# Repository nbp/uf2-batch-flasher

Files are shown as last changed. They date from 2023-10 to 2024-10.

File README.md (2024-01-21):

# UF2 Batch Flasher

The UF2 Batch Flasher is meant to provide a way to loop over up to 64 devices,
in order to flash all the 64 devices with a single
[UF2](https://github.com/microsoft/uf2) image. Using a Raspberry Pi Pico, and 64
USB A ports, the RP2040 will select one port at a time, and copy the transmitted
image to each device.

The alternative is to find the next cable, find the board at the end of it,
press a button, plug the cable while pressing the button, type a command / drag
a file over, unplug the device and repeat this 63 times. Not only this error
prone but this is time intensive and would probably take half an hour to iterate
over that many devices manually.

Picture of the First version of the UF2 Batch Flasher board

# Building the Hardware

The board design is designed using [KiCad](https://www.kicad.org/) and the
sources are located under the PCB directory. The Vendor links to Mouser are
listed as part of the component descriptions, and as of beginning of 2024, there
is [approximately 270€ of components and
PCB](https://www.nbp.name/projects/uf2-batch-flasher/#bill-of-material) to build
a single one.

# Building the Firmware

The firmware dependencies are managed with [Nix](https://nixos.org/) and
composed of the [Pico-SDK](https://github.com/raspberrypi/pico-sdk),
[Cyw43-driver](https://github.com/georgerobotics/cyw43-driver),
[LwIP](https://github.com/lwip-tcpip/lwip),
[TinyUSB](https://github.com/hathach/tinyusb) and
[Pico-PIO-USB](https://github.com/sekigon-gonnoc/Pico-PIO-USB).

In the root of the repository, type the following command to start a development
environment:

```shell
$ nix develop
```

This development environement will setup the expected environment variable and
provide a few useful functions such as `build` and `flash`. Other commands for
debugging are available such as `start_uart`, `start_openocd` and
`start_gdb_core0`, and listed in `firmware/shell.nix`.

Before building, you should configure the Wifi network credential by creating
the file `firmware/wifi.cmake`. A template file is available at
`firmware/wiki.cmake.template`.

To build just type `build` in this new environement and it would invoke `cmake`
and generate its output in the `_build` directory.

Once everything is built, plug the Raspberry Pi Pico W while pressing the
BOOTSEL button in order to flash it with the newly built firmware.

To flash, type `flash` in the build environment. This command invoke picotool as
a super user, to have access to usb devices. This will ask for your user
credential in order to flash the image.

# Debugging

Once the image is flashed, if all is good a web page would be served by the Pico
W, at the IP of the device on the registered network. The firmware also has UART
output on pins 16 and 17 in case of problems with the network stack.

Using the debug probes, one can connect to the within the development
environment with the `start_openocd` and `start_gdb_core0` to debug the Web
server and `start_gdb_core1` to debug the USB Host. The UART output can be
watched with `start_uart`.

# Using

Once powered, a web page is provided by the device, which list the status of the
USB as they are iterated over.

First drag and drop a UF2 image in the dedicated area and the click the "Flash
All" button. The web page would then iterate over the 64 USB ports, check if any
devices are connected, and if any flash the image on each of them.

The status of the flashing process then updates as it goes the status of the USB
which are listed on the page.

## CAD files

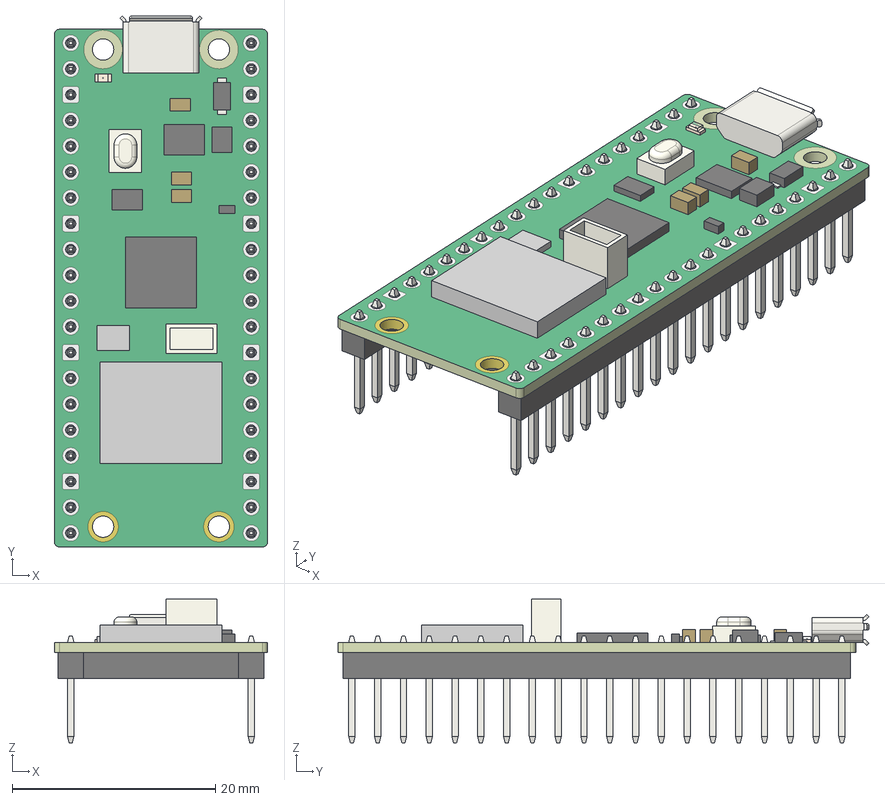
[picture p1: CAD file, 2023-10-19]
pcb/imports/RaspberryPi_Pico_STEP/RaspberryPi_Pico_WH_Socketed.step
21.0 x 52.3 x 14.1 mm
Pico_WH_Board
C1_47u
C2_47u
C21_47u
D1_MBR120VLSFT1G
D2_QSME-C194_Base
D2_QSME-C194_Phosphor
D2_QSME-C194_Lens
J1_690T505-x62-01x
J2_BM03B-SRSS-TB
L1_2u2
Q1_DMG1012T
SH1_CYW43439
SW1_TP-1221U-K9K5325
U1_RP2040
U2_RT6154AGQW
U3_W25Q16JVUXIQ
X1_X12M000000S096
DIP-40_W17.78mm_Header

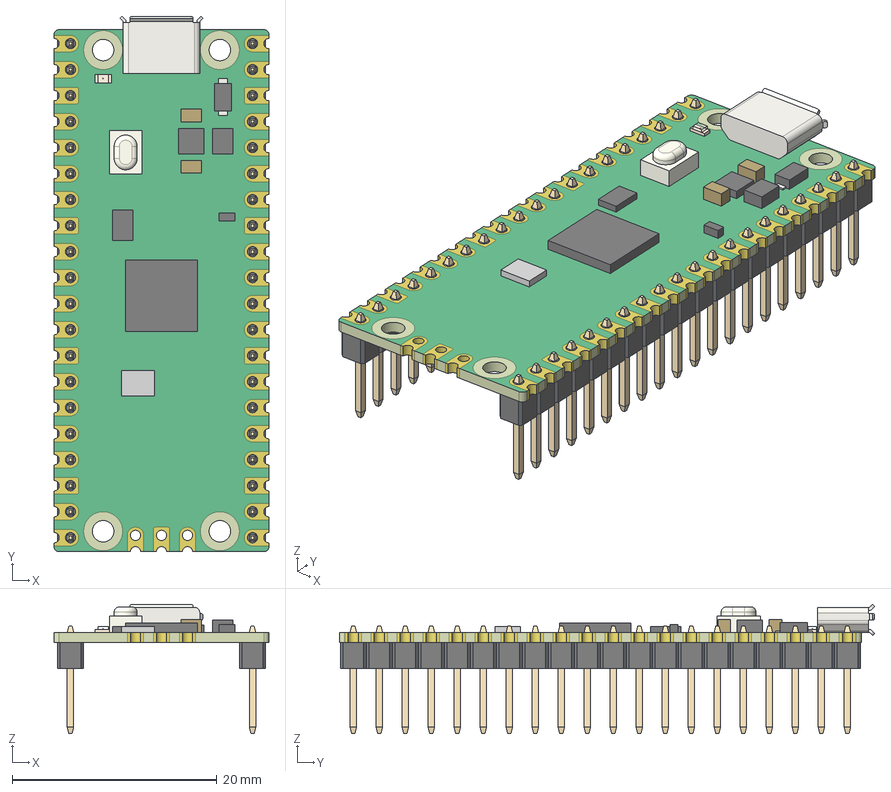
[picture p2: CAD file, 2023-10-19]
pcb/imports/RaspberryPi_Pico_STEP/RaspberryPi_Pico_AddedHeaders.step
21.0 x 52.3 x 12.6 mm
Pico_Board
C1_47u
C2_47u
D1_MBR120VLSFT1G
D2_QSME-C194_Base
D2_QSME-C194_Phosphor
D2_QSME-C194_Lens
J1_690T505-x62-01x
L1_2u2
Q1_DMG1012T
SW1_TP-1221U-K9K5325
U1_RP2040
U2_RT6150B-33GQW
U3_W25Q16JVUXIQ
X1_X12M000000S096
SIP-20_Header x 2

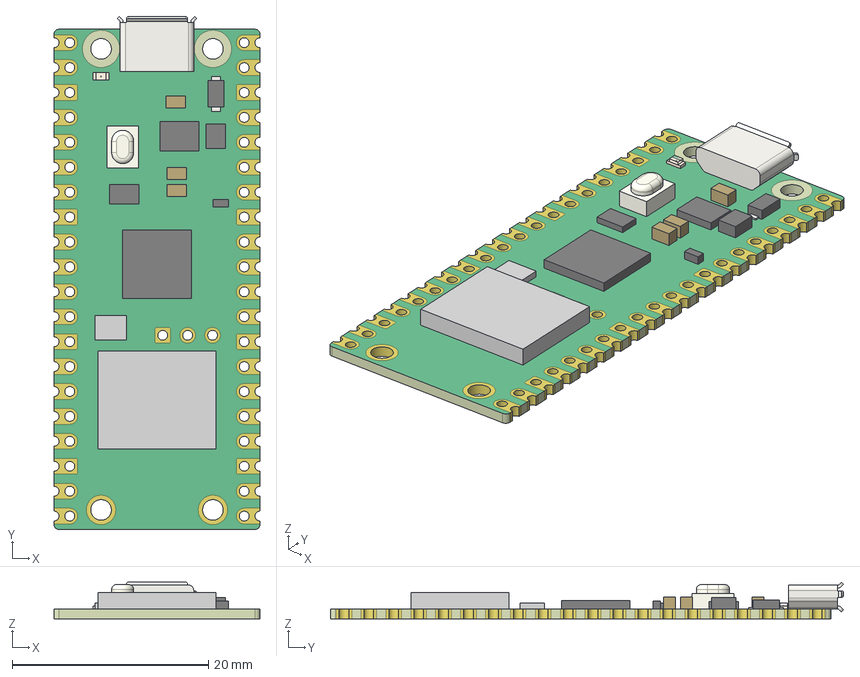
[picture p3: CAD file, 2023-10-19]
pcb/imports/RaspberryPi_Pico_STEP/RaspberryPi_Pico_W.step
21.0 x 52.3 x 3.75 mm
Pico_W_Board
C1_47u
C2_47u
C21_47u
D1_MBR120VLSFT1G
D2_QSME-C194_Base
D2_QSME-C194_Phosphor
D2_QSME-C194_Lens
J1_690T505-x62-01x
L1_2u2
Q1_DMG1012T
SH1_CYW43439
SW1_TP-1221U-K9K5325
U1_RP2040
U2_RT6154AGQW
U3_W25Q16JVUXIQ
X1_X12M000000S096

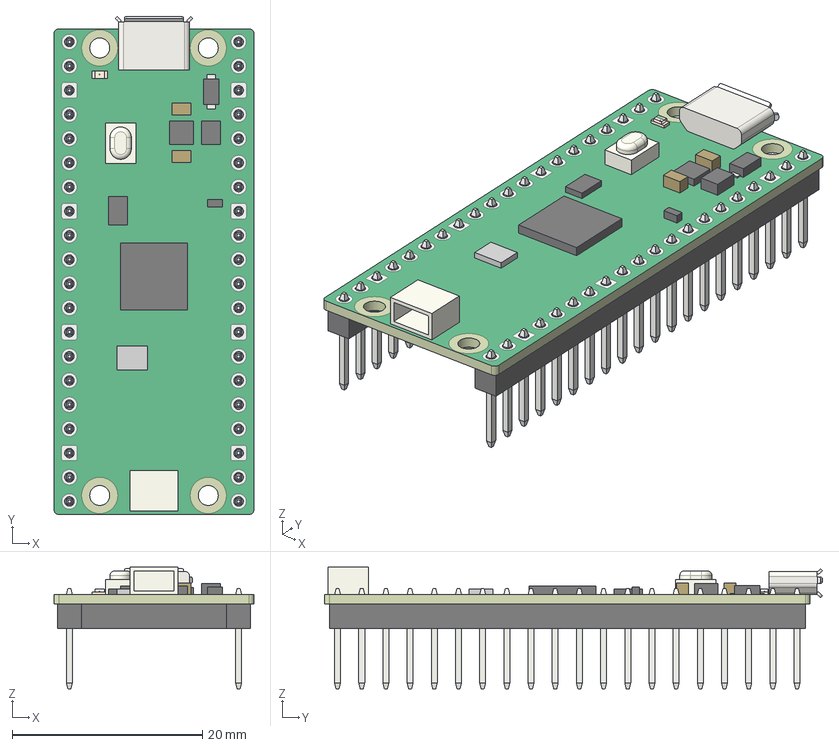
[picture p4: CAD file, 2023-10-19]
pcb/imports/RaspberryPi_Pico_STEP/RaspberryPi_Pico_H_Socketed.step
21.0 x 52.3 x 12.8 mm
Pico_H_Board
C1_47u
C2_47u
D1_MBR120VLSFT1G
D2_QSME-C194_Base
D2_QSME-C194_Phosphor
D2_QSME-C194_Lens
J1_690T505-x62-01x
J2_BM03B-SRSS-TB
L1_2u2
Q1_DMG1012T
SW1_TP-1221U-K9K5325
U1_RP2040
U2_RT6150B-33GQW
U3_W25Q16JVUXIQ
X1_X12M000000S096
DIP-40_W17.78mm_Header

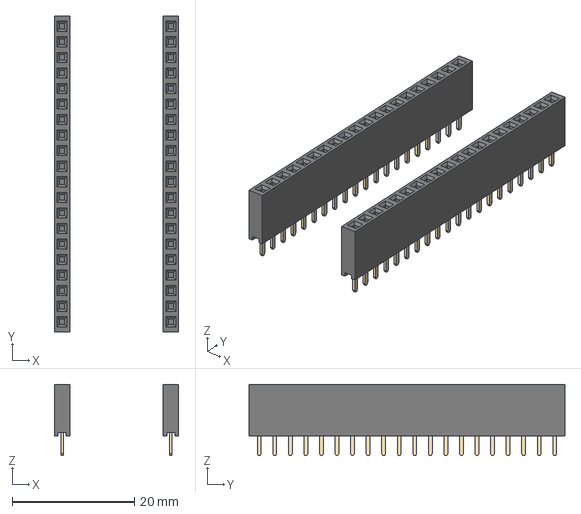
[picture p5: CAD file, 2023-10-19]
pcb/imports/RaspberryPi_Pico_STEP/DIP-40_W17.78mm_Socket.step
20.3 x 51.6 x 11.6 mm
SIP-20_Socket x 2

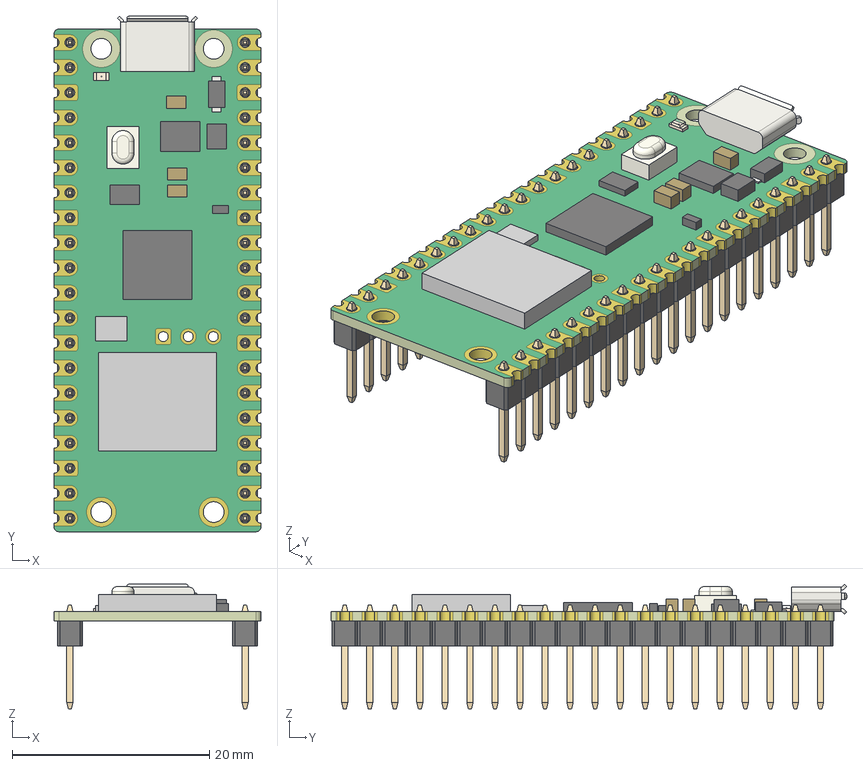
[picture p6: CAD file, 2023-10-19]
pcb/imports/RaspberryPi_Pico_STEP/RaspberryPi_Pico_W_AddedHeaders_Socketed.step
21.0 x 52.3 x 12.6 mm
Pico_W_Board
C1_47u
C2_47u
C21_47u
D1_MBR120VLSFT1G
D2_QSME-C194_Base
D2_QSME-C194_Phosphor
D2_QSME-C194_Lens
J1_690T505-x62-01x
L1_2u2
Q1_DMG1012T
SH1_CYW43439
SW1_TP-1221U-K9K5325
U1_RP2040
U2_RT6154AGQW
U3_W25Q16JVUXIQ
X1_X12M000000S096
SIP-20_Header x 2

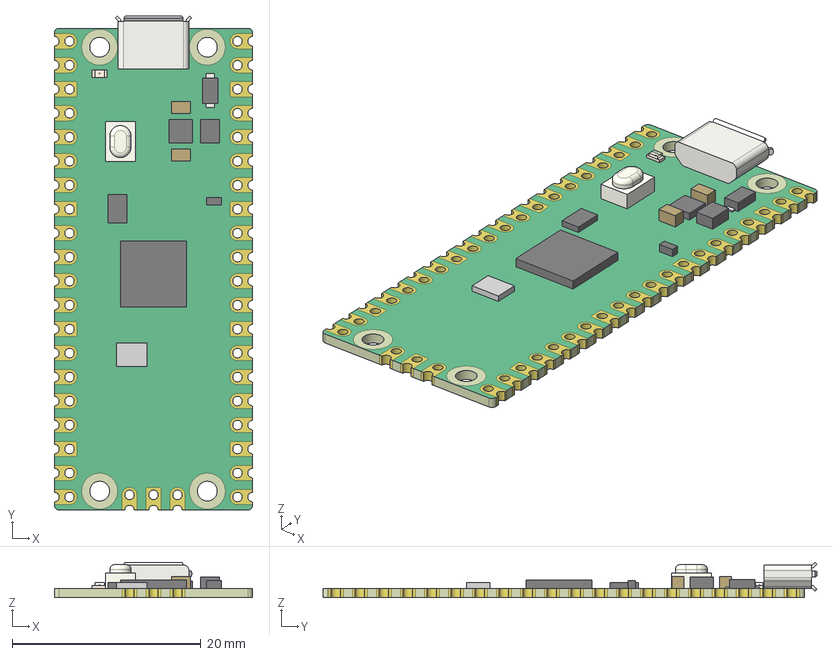
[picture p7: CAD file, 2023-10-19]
pcb/imports/RaspberryPi_Pico_STEP/RaspberryPi_Pico.step
21.0 x 52.3 x 3.75 mm
Pico_Board
C1_47u
C2_47u
D1_MBR120VLSFT1G
D2_QSME-C194_Base
D2_QSME-C194_Phosphor
D2_QSME-C194_Lens
J1_690T505-x62-01x
L1_2u2
Q1_DMG1012T
SW1_TP-1221U-K9K5325
U1_RP2040
U2_RT6150B-33GQW
U3_W25Q16JVUXIQ
X1_X12M000000S096

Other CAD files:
pcb/imports/RaspberryPi_Pico_STEP/RaspberryPi_Pico_WH.step
pcb/imports/RaspberryPi_Pico_STEP/RaspberryPi_Pico_H.step
pcb/imports/RaspberryPi_Pico_STEP/RaspberryPi_Pico_AddedHeaders_Socketed.step
pcb/imports/RaspberryPi_Pico_STEP/RaspberryPi_Pico_W_AddedHeaders.step

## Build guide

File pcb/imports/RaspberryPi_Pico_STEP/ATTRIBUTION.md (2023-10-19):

# Ki-Lime Pi Pico project attributions

## Peter S. Hollander

Model, footprint, and symbol [source files and documentation](https://gitlab.com/recursivenomad/ki-lime-pi-pico)
created and compiled by Peter S. Hollander between 2022 and 2023, and made
freely available under the [*MIT No Attribution*](https://opensource.org/license/mit-0/) license.

## Melissa Lee

Source project title "Ki-Lime Pi" created by Melissa Lee in 2022, and donated
with unconditional permission 🥧

## Markus Gyger

Comprehensive alternate pin definitions as defined in the RP2040 datasheet
inspired by the [schematic symbol](https://gitlab.com/mgyger/kicad-symbols/-/blob/pico/MCU_Module.kicad_sym)
created by Markus Gyger.

## Raspberry Pi

Original assets which were referenced for geometry/organisation (model, symbol,
footprint) acquired from Raspberry Pi in 2022 via:

- [Raspberry Pi Pico Datasheet](https://datasheets.raspberrypi.com/pico/pico-datasheet.pdf)
  - Pico Model: <https://datasheets.raspberrypi.com/pico/Pico-R3-step.zip>
- [Raspberry Pi Pico W Datasheet](https://datasheets.raspberrypi.com/picow/pico-w-datasheet.pdf)
  - Pico W Model: <https://datasheets.raspberrypi.com/picow/PicoW-step.zip>
- [RP2040 Datasheet](https://datasheets.raspberrypi.com/rp2040/rp2040-datasheet.pdf)
- [Hardware design with the RP2040](https://datasheets.raspberrypi.com/rp2040/hardware-design-with-rp2040.pdf)
  - RP2040 Symbol: <https://datasheets.raspberrypi.com/rp2040/Minimal-KiCAD.zip>
  - Pico Footprint: <https://datasheets.raspberrypi.com/rp2040/VGA-KiCAD.zip>
  - Pico W Footprint: <https://datasheets.raspberrypi.com/rp2040/VGA-PicoW-KiCAD.zip>

&nbsp;

# Tools utilized

- [KiCad](https://www.kicad.org/) - Footprint/symbol library design
- [FreeCAD](https://www.freecad.org/) - Parametric 3D modelling
  - [KiCad StepUp addon](https://github.com/easyw/kicadStepUpMod) - VRML model exporting
- [VSCodium](https://vscodium.com/) - VRML model material bulk editing

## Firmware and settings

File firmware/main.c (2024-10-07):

#include <stdbool.h>
#include <stdint.h>
#include <stddef.h>
#include <stdio.h>
#include <stdlib.h> // calloc

#include "hardware/xosc.h"
#include "pico/stdlib.h"

#include "pico/bootrom.h" // reset_usb_boot

#include "usb_host.h"
#include "tcp_server.h"
#include "web_server.h"
#include "pipe.h"
#include "stdio_web.h"

#include "input.h"

int main() {
  // Initialize the cristall oscillator. This is necessary to have a minimal
  // clock drift and jitter. Then initialize the clock at a multiple of the USB
  // 12 Mbits/s (x10) for bit-banging USB using PIO.
  xosc_init();
  set_sys_clock_khz(120000, true);

  // Create stdio drivers to output printed content to either a UART interface
  // or the web interface.
  stdio_uart_init();
  printf("STDIO UART initialized!\n");
  stdio_init_web();
  printf("STDIO Web initialized!\n");

  // Initialize pipe communication between the 2 cores.
  pipes_init();
  printf("Pipes across cores initialized!\n");

  // Setup USB devices.
  usb_host_setup();

#if defined(USE_TCP_SERVER)
  // Setup the TCP server.
  if (!tcp_server_setup()) {
    reset_usb_boot(0, 0);
    return 1;
  }

  // Core 0 main loop.
  printf("Starting TCP server loop.\n");
  tcp_server_loop();
#else
  // Setup the Web server.
  if (!web_server_setup()) {
    reset_usb_boot(0, 0);
    return 1;
  }

  // Core 0 main loop.
  printf("Starting Web server loop.\n");
  web_server_loop();
#endif

  // Use the on-board LED to report the data status of the USB line.
  led_init();


  return 0;
}

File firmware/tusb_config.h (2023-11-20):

// This file is used by TinyUSB library to register the configuration of the board.

#ifndef TUSB_CONFIG_H
#define TUSB_CONFIG_H

//--------------------------------------------------------------------
// COMMON CONFIGURATION
//--------------------------------------------------------------------

// defined by compiler flags for flexibility
#ifndef CFG_TUSB_MCU
#error CFG_TUSB_MCU must be defined
#endif

#ifndef CFG_TUSB_OS
#define CFG_TUSB_OS           OPT_OS_NONE
#endif

#ifndef CFG_TUSB_DEBUG
#ifndef NDEBUG
#define CFG_TUSB_DEBUG        3
#else
#define CFG_TUSB_DEBUG        0
#endif
#endif

//--------------------------------------------------------------------
// DEVICE CONFIGURATION (disabled)
//--------------------------------------------------------------------

// TODO: Enable the device CDC in order to switch to BOOTSEL mode as the
// stdio_usb library does using the baud rate, as well as re-implementing the
// stdio_usb output.

// RHPort number used for device can be defined by board.mk, default to port 0
#ifndef BOARD_TUD_RHPORT
#define BOARD_TUD_RHPORT      0
#endif

// RHPort max operational speed can defined by board.mk
#ifndef BOARD_TUD_MAX_SPEED
#define BOARD_TUD_MAX_SPEED   OPT_MODE_DEFAULT_SPEED
#endif

// Enable Device stack, Default is max speed that hardware controller could support with on-chip PHY
#define CFG_TUD_ENABLED       0
#define CFG_TUD_MAX_SPEED     BOARD_TUD_MAX_SPEED

// No Special section for the RP2040 while using DMA.
#define CFG_TUD_MEM_SECTION
#define CFG_TUD_MEM_ALIGN        __attribute__ ((aligned(4)))

#ifndef CFG_TUD_ENDPOINT0_SIZE
#define CFG_TUD_ENDPOINT0_SIZE    64
#endif

//------------- CLASS -------------//
#define CFG_TUD_CDC              0

// CDC FIFO size of TX and RX
#define CFG_TUD_CDC_RX_BUFSIZE   (TUD_OPT_HIGH_SPEED ? 512 : 64)
#define CFG_TUD_CDC_TX_BUFSIZE   (TUD_OPT_HIGH_SPEED ? 512 : 64)

// CDC Endpoint transfer buffer size, more is faster
#define CFG_TUD_CDC_EP_BUFSIZE   (TUD_OPT_HIGH_SPEED ? 512 : 64)

//--------------------------------------------------------------------
// HOST CONFIGURATION
//--------------------------------------------------------------------

// RHPort number used for host can be defined by board.mk, default to port 1
#ifndef BOARD_TUH_RHPORT
#define BOARD_TUH_RHPORT      1
#endif

// RHPort max operational speed can defined by board.mk
#ifndef BOARD_TUH_MAX_SPEED
#define BOARD_TUH_MAX_SPEED   OPT_MODE_DEFAULT_SPEED
#endif

// Enable Host stack, Default is max speed that hardware controller could support with on-chip PHY
#define CFG_TUH_ENABLED       1
#define CFG_TUH_MAX_SPEED     BOARD_TUH_MAX_SPEED

// Use pico-pio-usb as host controller for raspberry rp2040
#define CFG_TUH_RPI_PIO_USB   1

// Size of buffer to hold descriptors and other data used for enumeration
#define CFG_TUH_ENUMERATION_BUFSIZE 256

// No Special section for the RP2040 while using DMA.
#define CFG_TUH_MEM_SECTION
#define CFG_TUH_MEM_ALIGN           __attribute__ ((aligned(4)))

//------------- CLASS -------------//

// The UF2 batch flasher has 64 ports, which should be good enough for now.
#define CFG_TUH_HUB                 1
#define CFG_TUH_DEVICE_MAX          1
// (CFG_TUH_HUB ? 4 : 1) // hub typically has 4 ports
// #define CFG_TUH_MSC_MAXLUN          1 // typically 4

// Setup the current Raspberry Pi Pico to be used as a host for reading the
// file system of the device.
#define CFG_TUH_MSC                 1 // Mass Storage Class

// The RP2040 can be configured by the host to be reprogrammed, using the
// following macros:
//  - PICO_STDIO_USB_ENABLE_RESET_VIA_VENDOR_INTERFACE
//  - PICO_STDIO_USB_RESET_INTERFACE_SUPPORT_RESET_TO_BOOTSEL
//  - PICO_STDIO_USB_ENABLE_RESET_VIA_BAUD_RATE
//
// These macros are enabled by default when stdio_usb is used.
#define CFG_TUH_CDC                 1 // Communication Device Class

#define CFG_TUH_HID                 0 // keyboard / mouse
#define CFG_TUH_MIDI                0 // MIDI streaming interface.
#define CFG_TUH_VENDOR              0
// #define CFG_TUH_HID_EPIN_BUFSIZE    64
// #define CFG_TUH_HID_EPOUT_BUFSIZE   64

#endif // !TUSB_CONFIG_H

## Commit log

2023-10-19 Add UF2 Batch flasher board design
    [DIP-40_W17.78mm_Socket.step, RaspberryPi_Pico.step, RaspberryPi_Pico_AddedHeaders.step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]
2023-10-20 Add extra space and GND space below tracks.
2023-10-20 Briefly document and add the OSHW logo.
    [level1.kicad_sch, level2.kicad_sch, uf2-batch-flasher.kicad_sch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]
2023-10-20 Space out the SEL and Enable vias under the pico.
2023-10-20 Add alignment holes in the stencil.
2023-10-20 Move stencils alignment holes to be within the edges, using mounting holes and through holes of a few USB plugs.
2023-10-25 Alignment holes did not appear on the PCB preview of Aisler :/
2023-11-12 Fix Select pins mapping.
    Both the selector and demultiplexer are used to enable/disable the power
    and data pins. If the mapping of pins is not identical between the 2
    then we would enable the power pins of one USB port and the data pins of
    another.
    This patch changes that such that components which are closer to the
    Pico are using the high-power bits while components which are further
    down the tree are using the low bits. This way the enable pins are
    correctly ordered as specified in the datasheets of both components.
    Previously we were using the lowest bits, this would have been if
    the enable pins were mapped accordingly. Which was not the case.
    This change include changes in the schemat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
    [level1.kicad_sch, level2.kicad_sch, uf2-batch-flasher.kicad_sch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]
2023-11-18 Add first draft of the firmware.
    This firmware for the UF2 Batch Flasher provides a Web interface for the
    Raspberry Pi Pico W.
    The Web interface reports the status of the connected USB drives, and
    combined with the web client, the image to be flashed can be repeated to
    each device without adding cycles to the uf2 batch flasher flash.
    The uf2 batch flasher listen for HTTP request to wait for instructions
    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
2023-11-18 Handle cases where flashing the USB device does not complete.
2023-11-20 Enable float implementation to unblock pio usb.
    Pio USB implementation is using floating point operations to compute the number
    of cycles for the USB clock. Preventing uses of floating point caused the code
    to freeze and prevented the rest from being executed.
    [tusb_config.h]
2023-11-20 Use pins 16 & 17 for UART stdout/stdin.
    By default the pins 0 and 1 are used for UART, but these were conflicting with
    D+/D- pins.
    Moving UART to unassigned pins is useful to debug while the firmware is still in
    a prototype stage and the code is not fully working.
2023-11-20 Manually callback the polling of network activity.
    As this firmware uses both cores, in order to handle USB host interaction on
    core 1 and Web server interactions on core 0, we cannot rely on the threadsafe
    integration of cyw43 as this requires to have one other core available.
    Thus, instead we manually poll from the core 0 thread.
2023-11-20 Add debugging tools in the `nix develop` shell.
    minicom is useful for displaying the content coming through UART.
    openocd is useful for handling the debugprobe / picoprobe.
    gdb is useful for introspecting memory content.
2023-11-20 Properly report status via the ssi_handler.
    The ssi_handler had some first draft issues, this is now fixed by
    properly appending data and counting it properly. Also the stdout is now
    properly processed by renaming the file with one of the extensions
    supported by the SSI handler.
    Testing the USB with another Pico, everything seems to work almost out
    of the box, except that once switching the connected device to BOOTSEL
    mode, the TinyUSB host does not unmount the device and stays in CDC.
    [tusb_config.h]
2023-12-29 firmware: Fix enable pin logic, to match the hardware.
2023-12-29 firmware: Toggle USB data pins to move from CDC to MSC mount.
    The Raspberry Pi Pico / RP2040, has a mode where we can set the BAUD rate at
    1200Hz, to programmatically select the BOOTSEL mode, where it emulates a storage
    device.
    However TinyUSB does not take notice of this mode switch. Thus, we disable the
    data pins until TinyUSB unmount the device from the CDC mode, and renable them
    such that it can now consider it as an MSC mode. Such that we can flash the
    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
2023-12-29 firmware: Add missing select pin and fix off-by-1 on power and data pins.
    The missing select pin, and the off-by 1 issue caused the power pin to remain 0
    most of the time keeping all LED on.
2023-12-29 firmware: select.cgi was not found.
    When the JS code attempted to select the next device the web server did not
    respond because it was explicitly match for `select` without extensions.
2024-01-09 firmware: Avoid toogle to avoid accidental unbalanced of USB mount status.
2024-01-09 firmware: Stream bytes from POST to USB using pbuf from LwIP.
    Previously the data was being copied over from the POST request to a pipe held
    in memory, before being pulled by the USB host core which would send the bytes
    over to the USB device. This techniques caused some packets drop as the pipe was
    not being emptied fast enough and locked the receiving function.
    Locking the receving function caused some packets drops which caused the flashed
    image to be smaller than the original image which had to be flashed.
    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
2024-01-13 pcb: Update the directory in which the board is located.
    [DIP-40_W17.78mm_Socket.step, RaspberryPi_Pico.step, RaspberryPi_Pico_AddedHeaders.step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]
2024-01-14 web interface: Avoid failures, and allow reduced timeout.
    Previously the hardware could stop by waiting for a status code which had
    already been, then replaced. This implies that one would always wait for the
    last stable status instead of waiting for the first status code.
    By being able to wait for the last status code, we can increase the timer for
    the last status code, while decreasing the timer for the first status code by
    checking for inequality given that the most important status code are monotonic.
2024-01-14 firmware: Wait to account for the reboot in BOOTSEL mode.
    When we send the signal to put the device in BOOTSEL mode, by the time it
    finishes its initialization, TinyUSB would have recorded the device as nothing
    and then do not update its status after that.
    By disabling the USB data lines, we force TinyUSB to ignore the intermediate
    state and only consider the device when it is fully rebooted in BOOTSEL mode.
    Thus, being ready to be mounted as a mass storage class device.
2024-01-18 firmware: Do not f_sync after each f_write.
    When dealing with a microcontroller and not a flash drive, we want to ensure
    that each chunk is full of data that we intend to write.
    f_sync call, while helping with flash drives, causes issues with microcontroller
    devices being flashed with UF2 images. USB msc will typically write 512 bytes at
    a time, except that the 512 bytes of UF2 represent a data structure which is
    then interpreted by the microcontroller. Using f_sync will send partially
    intialized data which has the potential of putting the microcontroller in a bad
    state and potentially crashing it.
    Thus this patch comments out the f_sync call within write_file_content to avoid
    this issue.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
2024-01-18 interface: use larger timeout to accomodate debug builds.
    Frequently, when using a lot of debug-printf, the timeout are not sufficient and
    the web interface schedule a device change before the USB host part got a chance
    to take it in consideration.
2024-01-20 firmware: usb: Throttle down the f_write calls to avoid failures.
    When using flash drive f_sync seems appropriate, however when using Raspberry Pi
    Pico, the f_sync calls cause errors in subsequent f_write calls. Thus we
    fallback on sleep_ms with a conservative sleeping time of 32ms per sector of 4
    kB.
2024-01-20 firmware: usb: Add tuh_sleep_ms function for actively waiting.
    When using sleep_ms, the MCU would no longer process any input coming from PIO,
    and thus might skip feedback from the connected device.
    The tuh_sleep_ms is an active loop which will loop until an absolute time, set
    at an offset in the future is reached. Thus effectively waiting until all tasks
    are completed.
    However, we should be careful about the fact that these function might reenter
    in a completely different state. This might also not be compatible with tuh
    implementations of these callbacks. Ideally we should limit test to queued usb
    tasks.
2024-01-20 firmware: Add new state to avoid looping back.
    When one flashing procedure is complete the USB device would restart after the
    completion of te UF2 image. However, this causes the USB host to request that
    the device is once more rebooted in BOOT select mode. The second BOOT select
    mode would not be problematic if it were to not update the usb status, leaving
    the system in a confused state.
    This change introduced DEVICE_SELECTED, set once a device is selected and before
    the DEVICE_BOOTSEL_REQUEST is reached. This way there is no loopback once the
    content is properly flashed.
    This change also clears all the USB states when starting the batch-flashing
    procedure as a way to avoid loading stale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
2024-01-21 firmware: usb: Do not attempt to reflash if the device reboots in MSC.
    When a device reboots in MSC, we would starts the inquiry of the device type
    before scheduling a FLASH_REQUEST. However, this might not be ideal if the web
    interface does not expect this state to come back.
2024-09-24 Use ARM halt instruction as a patchable value.
    By having a single patchable value which is replaced by the index of the board
    being flashed, we can write the same image on all boards, while having a single
    patched index to differentiate the boards and have slightly different behavior.
2024-09-28 Manage fetch calls to reduce pressure on the pico.
    When flashing devices, the `/flash` request is copying the image in the RAM of
    the flashing Pico, which does not leave a lot of margins for making additional
    requests which would attempt to allocate and fail.
    To avoid such failures, the automatic update of the status is disabled, an
    additional asyncTimeout is added and the wait_for_status_update is now in charge
    of spawning and killing the probing for status updates.
    Additional mechanism added in the process, such as a mutex implementation, which
    ensure that async operations are queued helps at preventing the overflow of
    request while one is being processed.
2024-10-07 Create a TCP server to send files using the command line.
    Doing a drag and drop of file and click on a button is slower than using the
    keyboard.
    Also having a TCP server allow throttle down the quantity of data in the buffers
    of the UF2 batch flasher, which has a limited amount of RAM compared to the
    image size that can fit in the flash of the micro controllers.
2024-12-28 Change the hostname of the board on the network.
